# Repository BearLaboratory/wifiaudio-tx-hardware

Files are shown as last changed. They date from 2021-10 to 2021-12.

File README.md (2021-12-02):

<h1 align="center" style="font-size:50px;font-weight:bold">WiFiAudio</h1>
<p align="center">基于WiFi的语音传输系统</p>
<p align="center">
    <a href="https://github.com/">
        
    </a>
    <a href="">
        
    </a> 
    <a href="https://github.com/BruceAKABear">
        
    </a>
</p>

整个系统在组织下分为及个仓库，请根据个人的需求参考：
- [语音发射端硬件](https://github.com/BearLaboratory/wifiaudio-tx-hardware)
- [发射端固件](https://github.com/BearLaboratory/wifiaudio-tx-firmware)
- [接收端硬件](https://github.com/BearLaboratory/wifiaudio-rx-hardware)
- [接收端固件](https://github.com/BearLaboratory/wifiaudio-rx-firmware)
- [PC端接收服务](https://github.com/BearLaboratory/wifiaudio-rx-pc)
- [PCM5102A解码验证模块](https://github.com/BearLaboratory/esp32-pcm51202-audio-hardware)

整个系统所使用的到的工具；
- [EDA工具使用开源免费的Kicad](https://www.kicad.org/)
- [固件开发使用简单的Arduino](https://www.arduino.cc/)

# 1. WiFi Audio TX （基于WiFi的无线麦克风发射端硬件）

WiFi Audio项目的目的是DIY一个开源且便宜的无线麦克风，辅助自己在拍摄视频时的收音。项目有几个根本点：
- 软件键全开源，方便大家对软硬件部分进行针对性的修改；
- 整体成本尽量低，为了达到这个目的在硬件设计部分，我舍弃了很多锦上添花的硬件（比如屏幕）；
- 基于WiFi，由于我个人想让麦克风能接入网络，因此抛弃了传统的UHF转而投入了WiFi的怀抱，正巧这两年芯片价格飞涨唯一还算正常的是上来乐鑫的ESP32系列芯片，价格便宜功能强大具有WiFi及蓝牙功能，因此选择它作为我们麦克的核心处理芯片。

麦克风选择我直接抛弃了传统模拟麦克风，虽然价格便宜，但是其外围电路较复杂，电路对声音音质的影响较大，不适合我们DIY。麦克风我测试的有两款一个是inmp441另一款是ics43434，后者是前者的替代品拥有更高的信噪比，我个人十分推荐使用ics43434。当然还有其他麦克风，奈何我自己没有买来测试，如果有小伙伴有自行测试，请将测试结果反馈给我 <mail>dengyi@dengyi.pro</mail>

# 2. 如何自行打板

整个硬件部分已完整打板测试，如果你使用嘉立创下单助手，直接将gebber目录下压缩文件上传即可，我推荐板材厚度选择1,1.6厚度过大，平时自己焊接过程中加热较麻烦。

如果你使用嘉立创smt服务时，上传坐标文件及bom_lc bom清单即可，如果出现错误，你需要手动去调整原件的方向等，确保焊盘准确即可，bom本身无任何问题。

# 2. 如何上传固件

固件部分，请参考其他仓库。对于固件我都是使用arduino进行编写，因此你需要安装arduino IDE，然后克隆固件仓库，然后进行编译上传。

需要特殊说明：因为我想尽量控制设备成本，所以没有板载烧录电路。进行固件的烧写需要使用我之前开发的ESP系列芯片烧录工具，具体的信息请参见这个仓库[ESP系列芯片烧录工具](https://github.com/BearLaboratory/downloader)

# 3. 如何使用

对于如何使用这部分，我推荐大家反复观看我的项目视频。因为我个人精力有限，每次readme文档我都写的比较糙（虽然多次召集负责写readme的小伙伴，但是并未成功）
# 4. 其他

整个项目在GPL协议下开源，禁止商用，商用请联系<mail>dengyi@dengyi.pro</mail>。

组织下所有开源项目均为个人出于兴趣进行开发及维护，并没有任何盈利，所以在维护频率上可能有很大的延迟，如果小伙伴们有兴趣可以发送邮件到<mail>dengyi@dengyi.pro</mail>与我个人联系或参与到开发中。同时非常欢迎对我的视频频道进行点赞或者关注，[B站](https://space.bilibili.com/402729300),[知乎](https://www.zhihu.com/people/deng-yi-92-16/columns),[youtube](https://www.youtube.com/channel/UCXvLKESzLbINYVe9J8rXerQ)

硬件可以个人自行在嘉立创下单打板，如果需要成品请直接在咸鱼搜索用户**BLab大熊实验室**，由于是非职业卖家，快递费由系统自行计算我做不了主还请谅解。

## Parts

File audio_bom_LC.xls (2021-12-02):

Comment型号 | Designator位号 | Footprint封装 | 嘉立创元件编号(可不要此列)
10uf | C2,C1, | 0603 | C19702
1uf | C4,C3, | 0603 | C15849
led-red | D1, | 0603 | C84263
led-green | D4,D3,D2, | 0603 | C72043
Conn_01x05_Female | J4, | 卧贴P=1.25mm | C225128
1k | R10,R7,R6,R4, | 0603 | C21190
0.4欧 | R3, | 0603 | C57344
1.2K | R5, | 0603 | C22765
10k | R8,R2,R1, | 0603 | C98220
100欧 | R9, | 0603 | C105588
SW_Push | SW2, | SMD | C115357
ESP-32S | U1, | SMD | C328062
tp4056 | U2, | ESOP-8 | C16581
ME6211C33M5G-N | U5, | SOT-23-5 | C82942
USB_C_Receptacle_USB2.0 | J1, | 8.94*7.3mm | C165948
SW_DPDT_x2 | SW1, | SMD | C221841

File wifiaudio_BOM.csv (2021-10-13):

Comment | Description | Designator | Footprint | LibRef | Pins | Quantity | PartNumber | url
10uf | desc | C2,C1, | C_0603_1608Metric | libref | 2 | 2
1uf | desc | C4,C3, | C_0603_1608Metric | libref | 2 | 2
led-red | desc | D1, | LED_0603_1608Metric | libref | 2 | 1
led-green | desc | D4,D3,D2, | LED_0603_1608Metric | libref | 2 | 3
Conn_01x05_Female | desc | J4, | JST_GH_SM05B-GHS-TB_1x05-1MP_P1.25mm_Horizontal | libref | 7 | 1
Conn_01x01_Female | desc | J6, | largepoint | libref | 1 | 1
1k | desc | R10,R7,R6,R4, | R_0603_1608Metric | libref | 2 | 4
0.4 | desc | R3, | R_0603_1608Metric | libref | 2 | 1
1.2K | desc | R5, | R_0603_1608Metric | libref | 2 | 1
10k | desc | R8,R2,R1, | R_0603_1608Metric | libref | 2 | 3
100 | desc | R9, | R_0603_1608Metric | libref | 2 | 1
SW_Push | desc | SW2, | bt-342 | libref | 2 | 1
ESP-32S | desc | U1, | ESP32-WROOM-32 | libref | 39 | 1
tp4056 | desc | U2, | SOIC-8-1EP_3.9x4.9mm_P1.27mm_EP2.29x3mm | libref | 13 | 1
ME6211C33M5G-N | desc | U5, | SOT-23-5 | libref | 5 | 1
Conn_01x01_Female | desc | J3,J2, | largepoint | libref | 1 | 2
Through Hole Items
USB_C_Receptacle_USB2.0 | desc | J1, | USB_C_Receptacle_HRO_TYPE-C-31-M-12 | libref | 22 | 1
Conn_01x06_Female | desc | J5, | PinHeader_1x06_P2.00mm_Vertical | libref | 6 | 1
SW_DPDT_x2 | desc | SW1, | SW_SPDT_PCM12 | libref | 9 | 1

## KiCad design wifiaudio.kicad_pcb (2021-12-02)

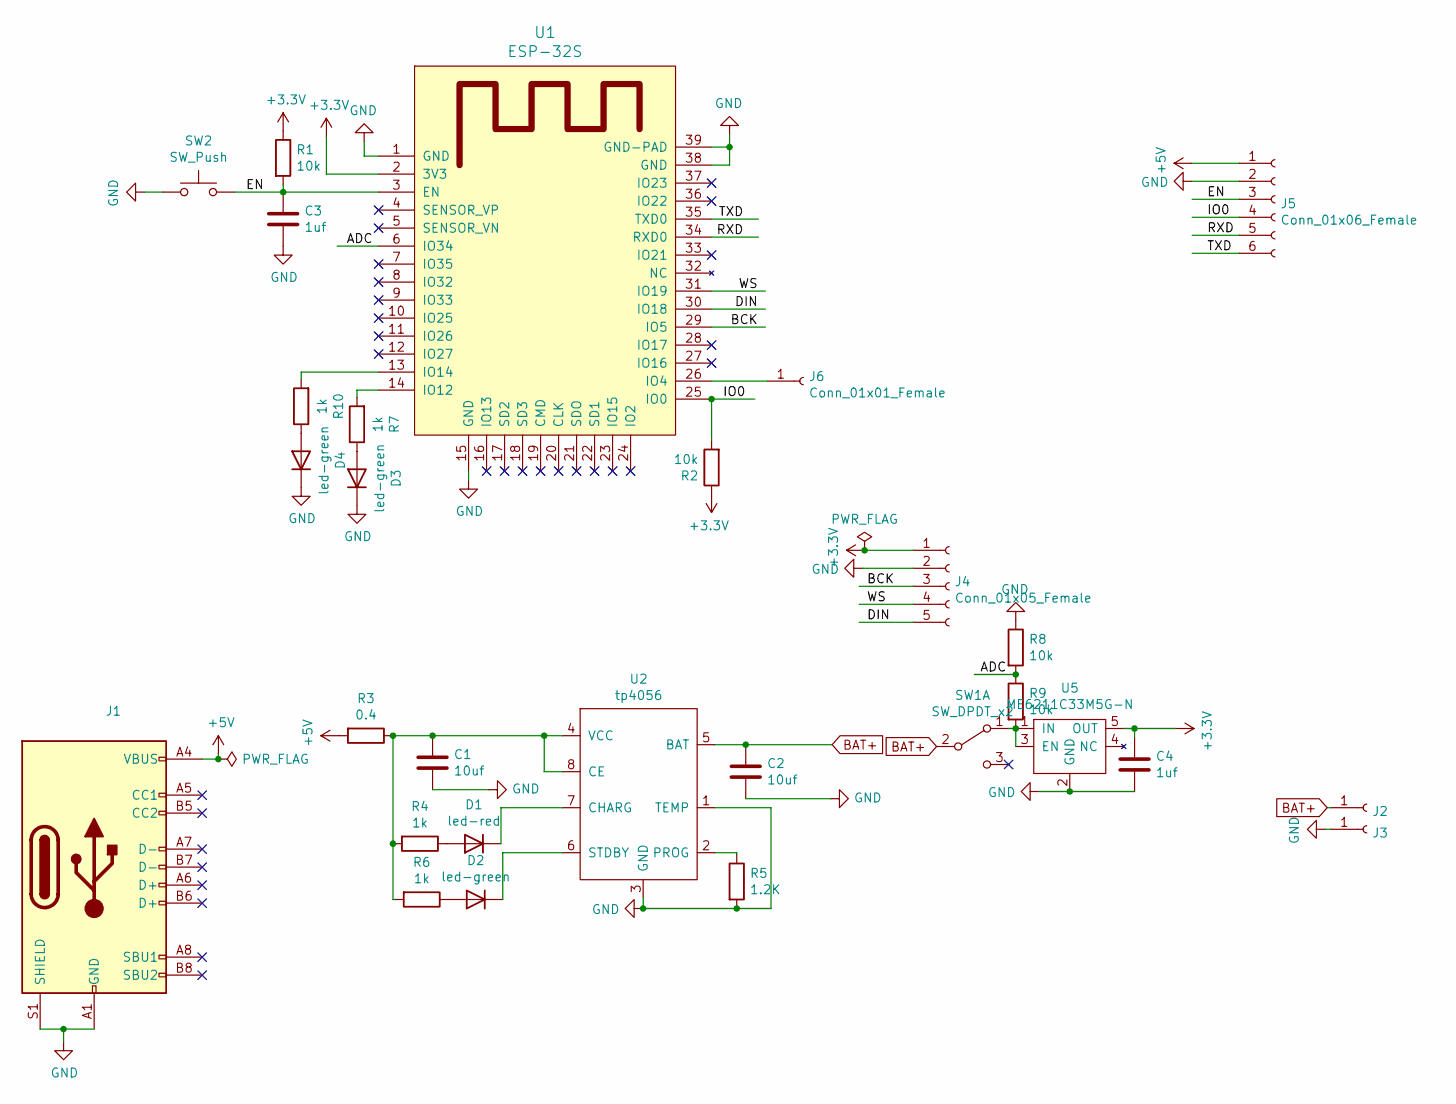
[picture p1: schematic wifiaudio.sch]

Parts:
C1, C2: 10uf; C_0603_1608Metric
C3, C4: 1uf; C_0603_1608Metric
D1: led-red; LED_0603_1608Metric
D2, D3, D4: led-green; LED_0603_1608Metric
J1: USB_C_Receptacle_USB2.0; USB_C_Receptacle_HRO_TYPE-C-31-M-12
J2, J3, J6: Conn_01x01_Female; largepoint
J4: Conn_01x05_Female; JST_GH_SM05B-GHS-TB_1x05-1MP_P1.25mm_Horizontal
J5: Conn_01x06_Female; PinHeader_1x06_P2.00mm_Vertical
R1, R2, R8, R9: 10k; R_0603_1608Metric
R3: 0.4; R_0603_1608Metric
R4, R6, R7, R10: 1k; R_0603_1608Metric
R5: 1.2K; R_0603_1608Metric
SW1: SW_DPDT_x2; SW_SPDT_PCM12
SW2: SW_Push; bt-342
U1: ESP-32S; ESP32-WROOM-32
U2: tp4056; SOIC-8-1EP_3.9x4.9mm_P1.27mm_EP2.29x3mm
U5: ME6211C33M5G-N; SOT-23-5

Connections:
+3V3: C4.1, J4.1, R1.1, R2.1, U1.2 (3V3), U5.5 (OUT)
+5V: J1.A4 (VBUS), J1.A9 (VBUS), J1.B4 (VBUS), J1.B9 (VBUS), J5.1, R3.2
/ADC: R8.2, R9.1, U1.6 (IO34)
/BCK: J4.3, U1.29 (IO5)
/DIN: J4.5, U1.30 (IO18)
/EN: C3.1, J5.3, R1.2, SW2.2, U1.3 (EN)
/IO0: J5.4, R2.2, U1.25 (IO0)
/RXD: J5.5, U1.34 (RXD0)
/TXD: J5.6, U1.35 (TXD0)
/WS: J4.4, U1.31 (IO19)
BAT+: C2.1, J2.1, SW1.2 (B), U2.5 (BAT)
GND: C1.2, C2.2, C3.2, C4.2, D3.1 (K), D4.1 (K), J1.A1 (GND), J1.A12 (GND), J1.B1 (GND), J1.B12 (GND), J1.S1 (SHIELD), J3.1, J4.2, J5.2, R5.2, R8.1, SW2.1, U1.1 (GND), U1.15 (GND), U1.38 (GND), U1.39 (GND-PAD), U2.1 (TEMP), U2.3 (GND), U5.2 (GND)
unnamed: C1.1, R3.1, R4.2, R6.2, U2.4 (VCC), U2.8 (CE)
unnamed: D1.1 (K), U2.7 (CHARG)
unnamed: D1.2 (A), R4.1
unnamed: D2.1 (K), U2.6 (STDBY)
unnamed: D2.2 (A), R6.1
unnamed: D3.2 (A), R7.1
unnamed: D4.2 (A), R10.1
unnamed: J6.1, U1.26 (IO4)
unnamed: R5.1, U2.2 (PROG)
unnamed: R7.2, U1.14 (IO12)
unnamed: R9.2, SW1.1 (A), U5.1 (IN), U5.3 (EN)
unnamed: R10.2, U1.13 (IO14)

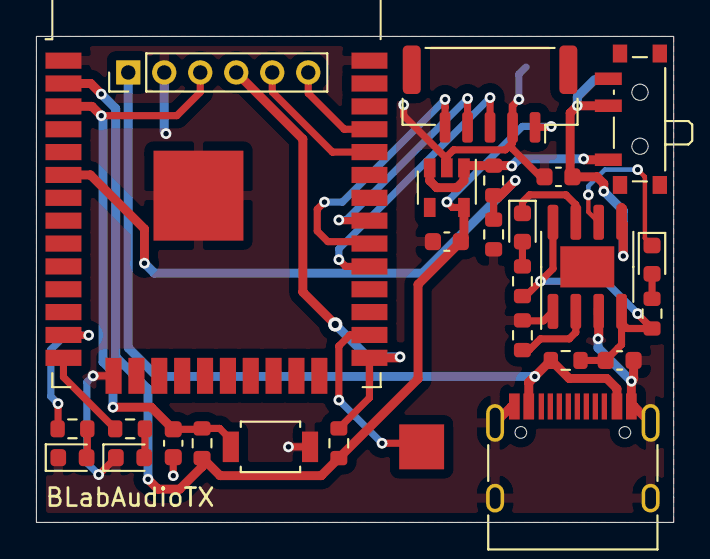
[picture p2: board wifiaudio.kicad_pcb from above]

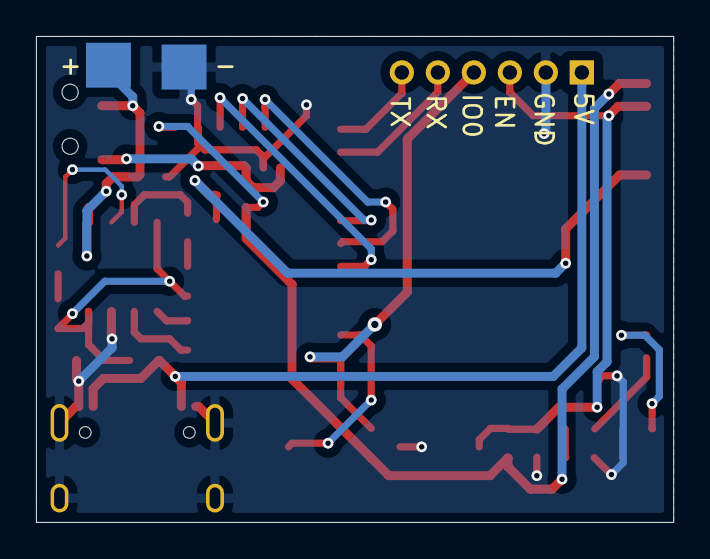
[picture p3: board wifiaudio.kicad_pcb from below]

Board: 2 copper layers, 35.4 x 27.0 mm, 29 parts (2 on the bottom side), 24 nets.

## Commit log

2021-10-13 初始化提交
    [wifiaudio-Bottom_Cu.gbr, wifiaudio-Bottom_Mask.gbr, wifiaudio-Bottom_Paste.gbr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]
2021-12-02 修改readme
    [audio_bom_LC.xls, wifiaudio.kicad_pcb, wifiaudio.sch]

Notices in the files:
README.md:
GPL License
